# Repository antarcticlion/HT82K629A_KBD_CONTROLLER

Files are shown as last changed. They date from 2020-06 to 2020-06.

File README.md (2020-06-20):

# HT82K629A_KBD_CONTROLLER
USB or PS/2 Keyboard controller board KiCad project

## Description
キーボードコントローラーIC HT82K629Aを使ったUSB PS/2両対応のコントローラー基板です。

## PCB Artwork
Rev0.4A  
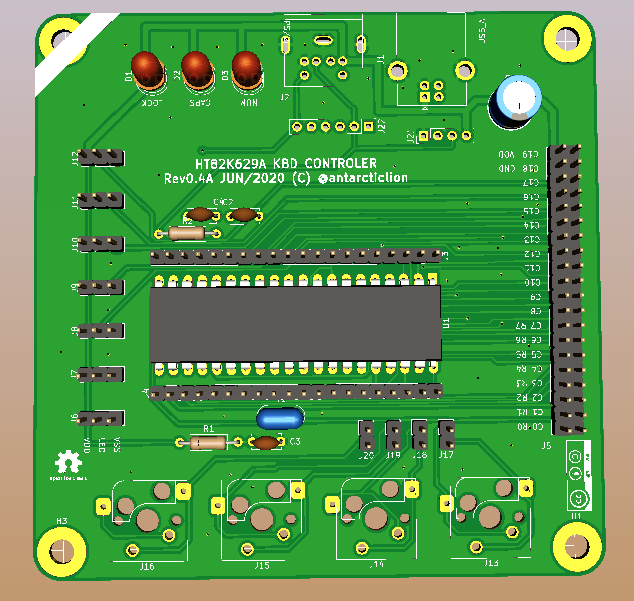
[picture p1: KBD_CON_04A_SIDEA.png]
Rev4A PCB_art 1
  
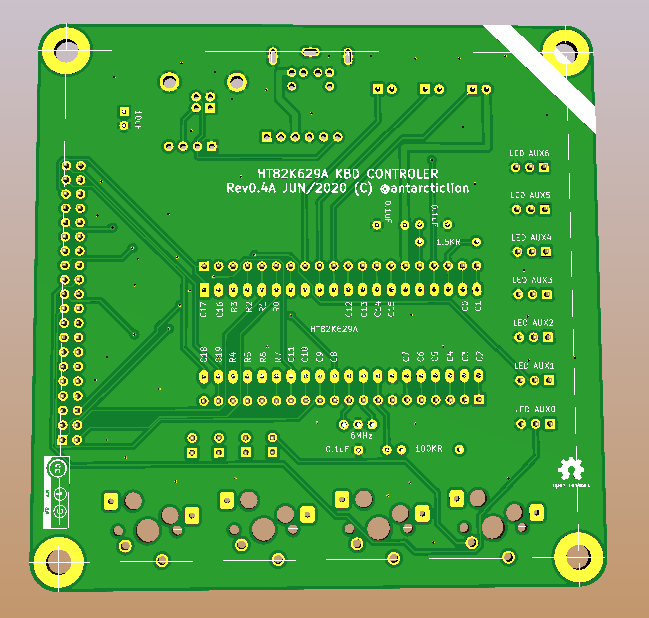
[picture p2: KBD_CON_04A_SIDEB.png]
Rev4A PCB_art 2
  

## 部品表(BOM)
| Ref | Name | Qty./Note |
|:---|:---|:---|
|C1 |Capacitor 10uF | N/A |
|C2-C4 |Capacitor 0.1uF CC or MLCC | 3pcs |
|R1 |Resistor 100KR 1/4W | N/A |
|R2 |Resistor 1.5KR 1/4W | N/A |
|F1 |Ceramic resonetor 6MHz | N/A |
|D1-D3 |LED | 3pcs |
|J1 |USB B full size connector | N/A |
|J2 |Mini-DIN 6p socket | N/A |
|J3-J4 |1x20 2.54mm pitch pinheader | 2pcs |
|J5 |2x20 2.54mm pitch pinheader | N/A |
|J6-J12 |1x3 2.54mm pitch pinheader | 7pcs |
|J13-J16 |Cherry MX key switch and/or hotswap parts | 4pcs |
|J17-J20 |1x2 2.54mm pitch pinheader | 4pcs |
|J21 |JST XH 4pin socket B4B-XH-A | N/A |
|J22 |JST XH 6pin socket B6B-XH-A | N/A |
|U1 | 40pin DIP IC SOCKET 600mil | N/A |
| N/A | HT82K629A 40DIP ic | install to U1 |

## License
MIT LicenseとCreative commons CC BY-SA 4.0のデュアルライセンスとします。

https://creativecommons.org/licenses/by-sa/4.0/deed.en

https://creativecommons.org/licenses/by-sa/4.0/deed.ja

---

Copyright 2020 @antarcticlion

Permission is hereby granted, free of charge, to any person obtaining a copy of this software and associated documentation files (the "Software"), to deal in the Software without restriction, including without limitation the rights to use, copy, modify, merge, publish, distribute, sublicense, and/or sell copies of the Software, and to permit persons to whom the Software is furnished to do so, subject to the following conditions:

The above copyright notice and this permission notice shall be included in all copies or substantial portions of the Software.

THE SOFTWARE IS PROVIDED "AS IS", WITHOUT WARRANTY OF ANY KIND, EXPRESS OR IMPLIED, INCLUDING BUT NOT LIMITED TO THE WARRANTIES OF MERCHANTABILITY, FITNESS FOR A PARTICULAR PURPOSE AND NONINFRINGEMENT. IN NO EVENT SHALL THE AUTHORS OR COPYRIGHT HOLDERS BE LIABLE FOR ANY CLAIM, DAMAGES OR OTHER LIABILITY, WHETHER IN AN ACTION OF CONTRACT, TORT OR OTHERWISE, ARISING FROM, OUT OF OR IN CONNECTION WITH THE SOFTWARE OR THE USE OR OTHER DEALINGS IN THE SOFTWARE.

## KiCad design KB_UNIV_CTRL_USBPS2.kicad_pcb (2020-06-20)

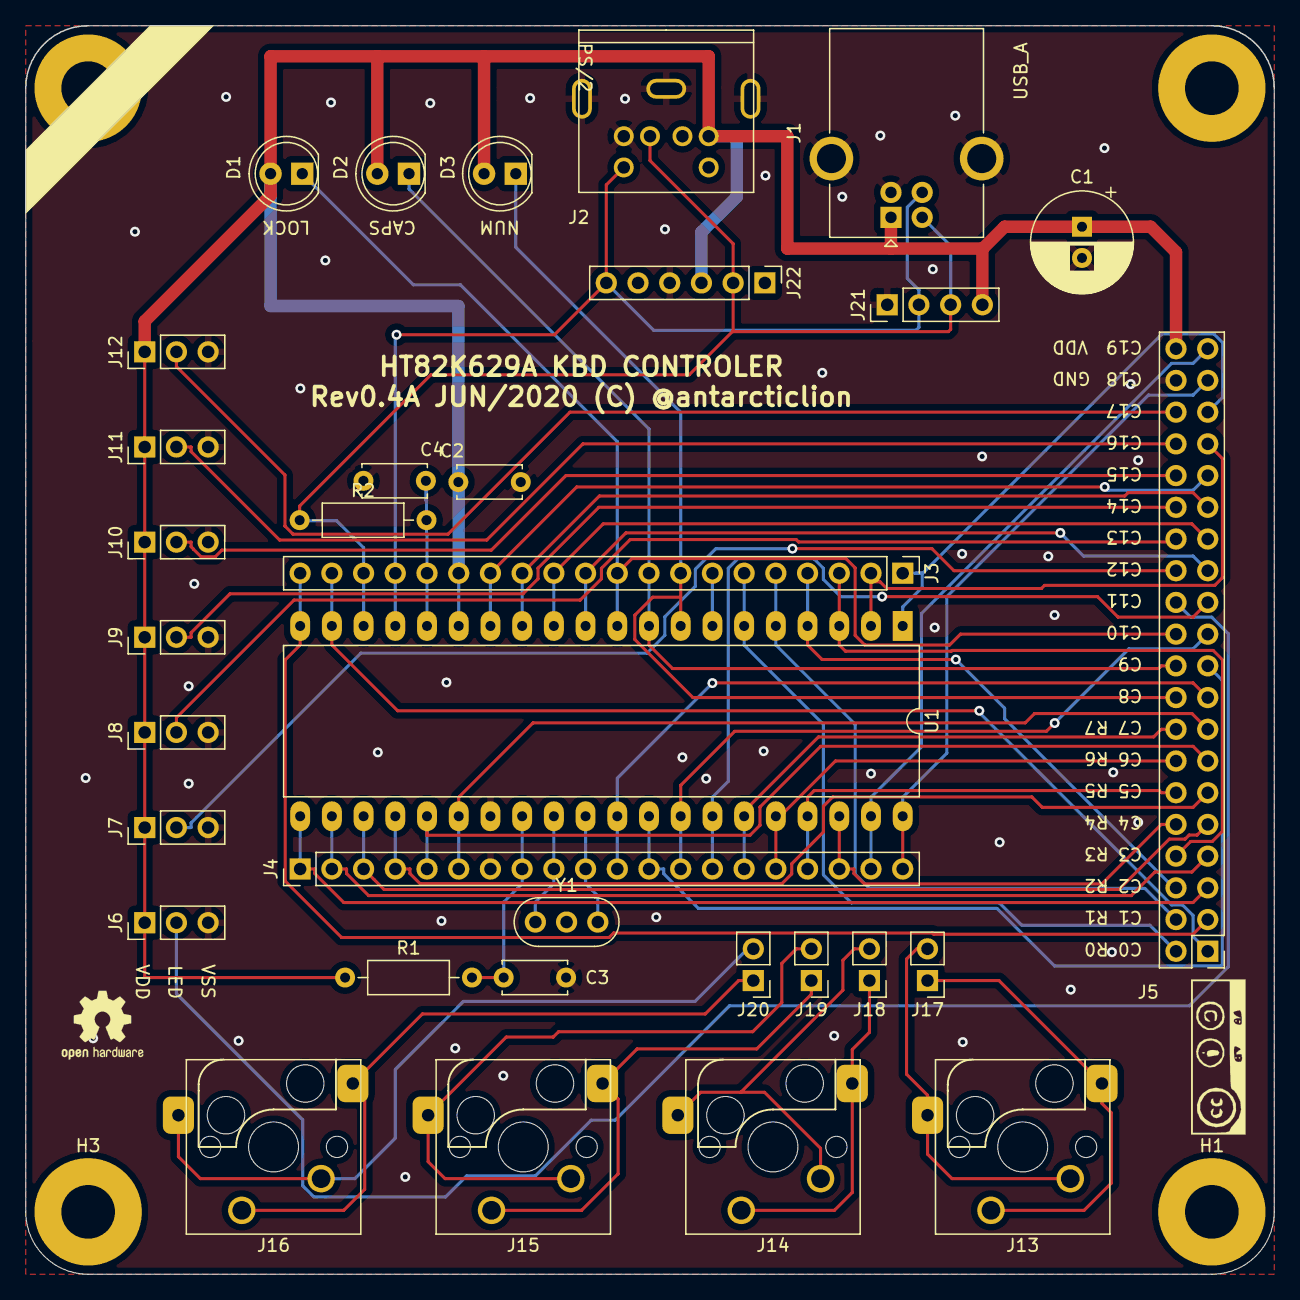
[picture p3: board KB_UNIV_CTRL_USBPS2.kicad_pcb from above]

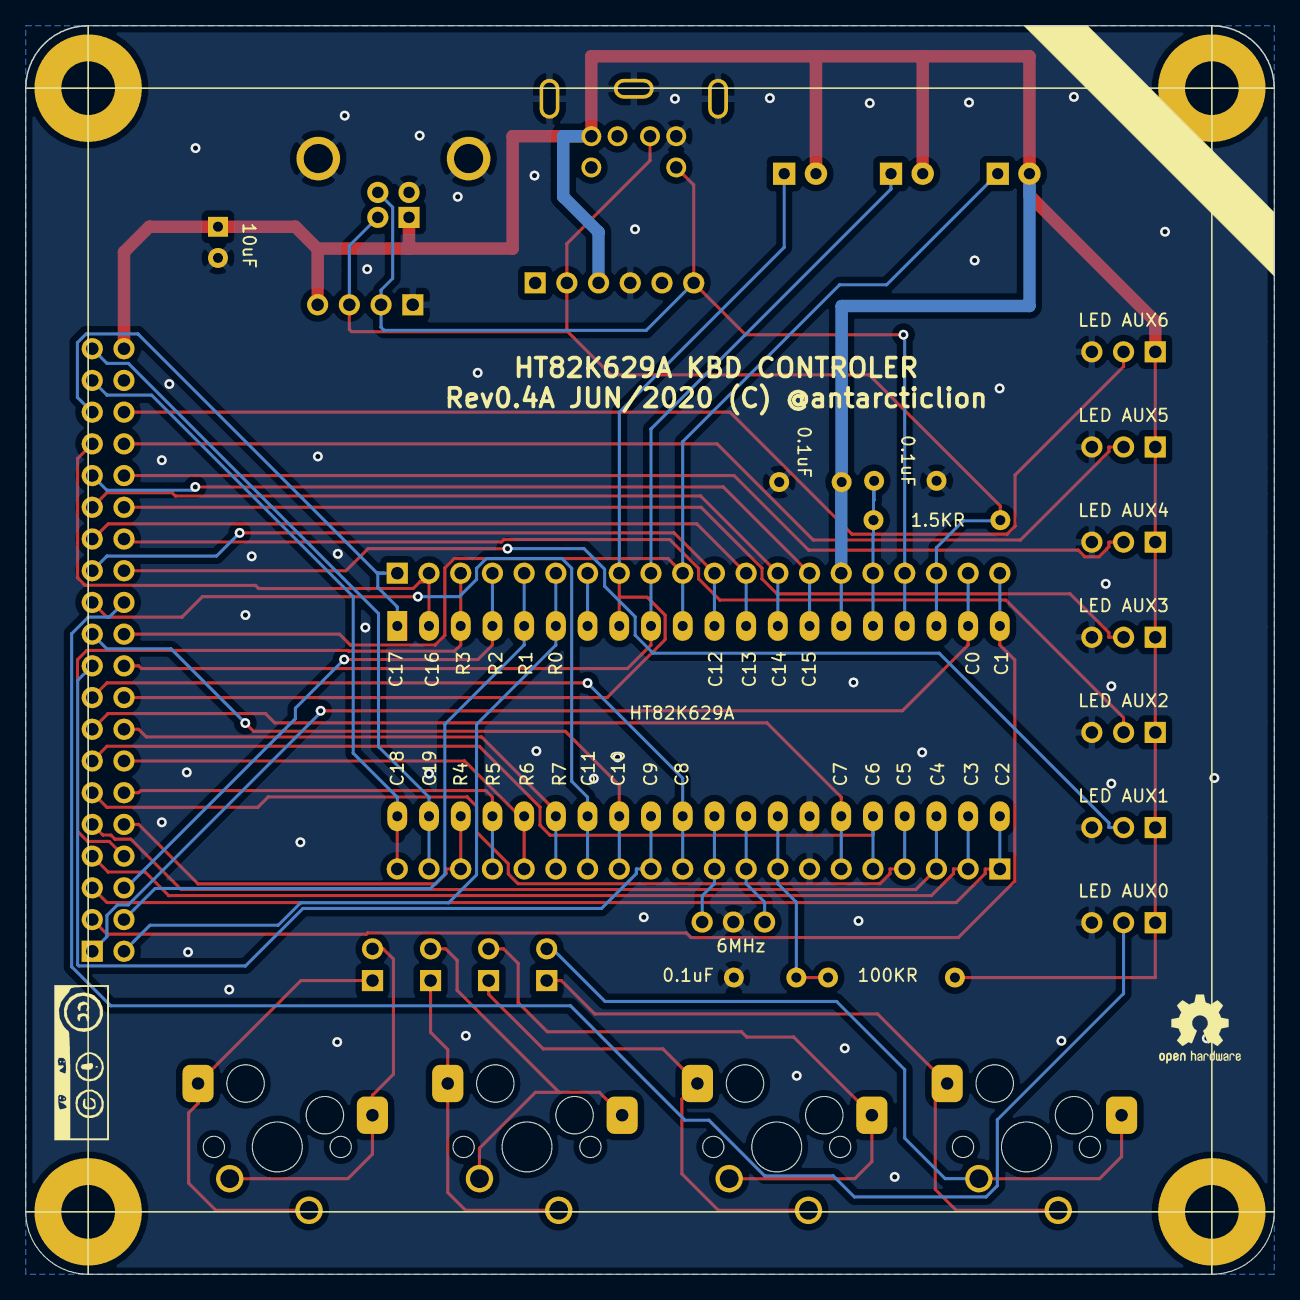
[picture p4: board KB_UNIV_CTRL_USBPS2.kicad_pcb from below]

Board: 2 copper layers, 100.0 x 100.0 mm, 41 parts (2 on the bottom side), 55 nets.

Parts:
C1: 10uF; CP_Radial_D8.0mm_P2.50mm
C2, C3, C4: 0.1uF; C_Disc_D5.0mm_W2.5mm_P5.00mm
D1, D2, D3: LED; LED_D5.0mm
G1, G2: LOGO; CCBYSA_LOGO2
G3, G4: OSHW-Logo2_7.3x6mm_SilkScreen
H1, H2, H3, H4: MountingHole; MountingHole_4.3mm_M4_Pad
J1: USB_A; USB_B_OST_USB-B1HSxx_Horizontal
J2: Mini-DIN-6; mini DIN 6 PCB
J3: CN_L; PinHeader_1x20_P2.54mm_Vertical
J4: CN_R; PinHeader_1x20_P2.54mm_Vertical
J5: Conn_02x20_Odd_Even; PinHeader_2x20_P2.54mm_Vertical
J6: LED AUX0; PinHeader_1x03_P2.54mm_Vertical
J7: LED AUX1; PinHeader_1x03_P2.54mm_Vertical
J8: LED AUX2; PinHeader_1x03_P2.54mm_Vertical
J9: LED AUX3; PinHeader_1x03_P2.54mm_Vertical
J10: LED AUX4; PinHeader_1x03_P2.54mm_Vertical
J11: LED AUX5; PinHeader_1x03_P2.54mm_Vertical
J12: LED AUX6; PinHeader_1x03_P2.54mm_Vertical
J13: KEY0; SW_Cherry_MX_1.00u_Hotswap
J14: KEY1; SW_Cherry_MX_1.00u_Hotswap
J15: KEY2; SW_Cherry_MX_1.00u_Hotswap
J16: KEY3; SW_Cherry_MX_1.00u_Hotswap
J17: K0; PinHeader_1x02_P2.54mm_Vertical
J18: K1; PinHeader_1x02_P2.54mm_Vertical
J19: K2; PinHeader_1x02_P2.54mm_Vertical
J20: K3; PinHeader_1x02_P2.54mm_Vertical
J21: Conn_01x04; PinHeader_1x04_P2.54mm_Vertical
J22: Conn_01x06; PinHeader_1x06_P2.54mm_Vertical
R1: 100KR; R_Axial_DIN0207_L6.3mm_D2.5mm_P10.16mm_Horizontal
R2: 1.5KR; R_Axial_DIN0207_L6.3mm_D2.5mm_P10.16mm_Horizontal
U1: HT82K629A; DIP-40_W15.24mm_LongPads
Y1: 6MHz; Resonator-3Pin_W8.0mm_H3.5mm

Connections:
#RESET: C3.1, J4.8, R1.2, U1.28
AUX0: J5.24, J6.2
AUX1: J5.26, J7.2
AUX2: J5.28, J8.2
AUX3: J5.30, J9.2
AUX4: J5.32, J10.2
AUX5: J5.34, J11.2
AUX6: J5.36, J12.2
C0: J3.19, J5.1, U1.19
C1: J3.20, J5.3, U1.20
C2: J4.1, J5.5, U1.21
C3: J4.2, J5.7, U1.22
C4: J4.3, J5.9, U1.23
C5: J4.4, J5.11, U1.24
C6: J4.5, J5.13, U1.25
C7: J4.6, J5.15, U1.26
C8: J4.11, J5.17, U1.31
C9: J4.12, J5.19, U1.32
C10: J4.13, J5.21, U1.33
C11: J4.14, J5.23, U1.34
C12: J3.11, J5.25, U1.11
C13: J3.12, J5.27, U1.12
C14: J3.13, J5.29, U1.13
C15: J3.14, J5.31, U1.14
C16: J3.2, J5.33, U1.2
C17: J3.1, J5.35, U1.1
C18: J4.20, J5.37, U1.40
C19: J4.19, J5.39, U1.39
CAPS_LED: D2.1, J3.9, J5.20, U1.9
D+: J1.3, J2.6, J3.17, J21.2, J22.6, U1.17
D-: J1.2, J2.2, J3.18, J21.3, J22.2, R2.1, U1.18
FN_SEL: J3.7, U1.7
NUM_LED: D3.1, J3.8, J5.18, U1.8
unnamed: J13.1, J17.1
unnamed: J13.2, J17.2
unnamed: J14.1, J18.1
unnamed: J14.2, J18.2
unnamed: J15.1, J19.1
unnamed: J15.2, J19.2
unnamed: J16.1, J20.1
unnamed: J16.2, J20.2
OSCI: J4.10, U1.30, Y1.3
OSCO: J4.9, U1.29, Y1.1
R0: J3.6, J5.2, U1.6
R1: J3.5, J5.4, U1.5
R2: J3.4, J5.6, U1.4
R3: J3.3, J5.8, U1.3
R4: J4.18, J5.10, U1.38
R5: J4.17, J5.12, U1.37
R6: J4.16, J5.14, U1.36
R7: J4.15, J5.16, U1.35
SCROLL_LED: D1.1, J3.10, J5.22, U1.10
V33O: C4.1, J3.16, R2.2, U1.16
VDD: C1.1, C2.1, D1.2, D2.2, D3.2, J1.1, J2.3, J3.15, J5.40, J6.1, J7.1, J8.1, J9.1, J10.1, J11.1, J12.1, J21.4, J22.3, R1.1, U1.15
VSS: C1.2, C2.2, C3.2, C4.2, J1.4, J1.5, J2.0, J2.4, J4.7, J5.38, J6.3, J7.3, J8.3, J9.3, J10.3, J11.3, J12.3, J21.1, J22.4, U1.27, Y1.2
